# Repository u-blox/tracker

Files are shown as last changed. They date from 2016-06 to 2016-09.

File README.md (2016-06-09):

# Introduction

This code is intended to be used with a Particle Electron board and a PAM-7Q GPS module, plus an ADXL345 accelerometer board (http://www.hobbytronics.co.uk/adxl345-breakout) to allow the GPS module to be powered-down when there is no motion.  It publishes data to the Particle cloud, which can then web-hooked on to the Azure cloud, or other clouds, for analysis.

More instructions to come...

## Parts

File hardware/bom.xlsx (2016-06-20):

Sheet: Tracker
Required
Identifier | Description | Value | Quantity | Manufacturer | Manufacturer Part Number | Supplier Link
MODULE | Particle Electron | --- | 1 | Particle |  | https://store.particle.io/collections/electron
MODULE | GPS module with built-in antenna | --- | 1 | u-blox | PAM-7Q | https://www.u-blox.com/en/product/pam-7q
MODULE | ADXL345 breakout board | --- | 1 | Hobbytronics | ADXL345-BB | http://www.hobbytronics.co.uk/sensors/accelerometer/adxl345-breakout
FET | FET, through hole | --- | 1 | Fairchild | NDP6020P | http://uk.rs-online.com/web/p/mosfet-transistors/8061230/
RESISTOR | Through-hole resistor, 6.5 mm (or less) body length to fit with PCB design | 10k | 1 | --- | --- | http://uk.rs-online.com/web/p/through-hole-fixed-resistors/7077745/
CONNECTOR | PCB header, JST PH B2B series, 2 mm pitch, 2 way, 1 row, through hole | --- | 2 | JST | B2B-PH-K-S(LF)(SN) | http://uk.rs-online.com/web/p/pcb-headers/8201422/
CONNECTOR | PCB socket, 0.1" pitch, 19 contacts, 1 row, through hole | --- | 2 | Samtec | CES-119-02-G-S | http://uk.farnell.com/samtec/ces-119-02-g-s/socket-2-54mm-1x20way/dp/1805643
CONNECTOR | PCB socket, 0.1" pitch, 8 contacts, 1 row, through hole | --- | 1 | Samtec | SSW-108-01-G-S | http://uk.rs-online.com/web/p/pcb-sockets/7655698/
CONNECTOR | PCB socket, 0.1" pitch, 5 contacts, 1 row, through hole | --- | 2 | Harwin | M20-7820546 | http://uk.rs-online.com/web/p/pcb-sockets/6816823/
CONNECTOR | PCB header, 0.1" pitch, 8 way, 1 row, through hole | --- | 1 | Amphenol | 77311-101-08LF | http://uk.rs-online.com/web/p/pcb-headers/6737483/
CONNECTOR | PCB header, 0.1" pitch, N way (you will need only one from the break-off strip), 1 row, through hole | --- | 1 | 3M | 2340-6211TG | http://uk.rs-online.com/web/p/pcb-headers/8277769/
BOX | ABS enclosure, IP54, 121 x 66 x 37 mm | --- | 1 | Hammond | 1591XXCBK | http://uk.rs-online.com/web/p/general-purpose-enclosures/7733139/
BOX ACCESSORIES | PC board self tapping screw no. 4 x 0.25" | --- | 1 bag | Hammond | 1593ATS100 | http://uk.rs-online.com/web/p/enclosure-accessories/0570691/
Optional
Identifier | Description | Value | Quantity | Manufacturer | Manufacturer Part Number | Supplier Link
BATTERY | Li-Po Battery with JST PH Series 2-pin B2B connector (2 mm pitch), 3.7 V, 2000 mAh dimensions 51 mm x 34 mm x 11.3 mm [NOTE 1] | --- | 1 | PKCell | LP103450
BATTERY | 3.7V Li-Po rechargeable battery, 2000 mAh, wire lead terminal [NOTE 2] | --- | 2 | MikroElectronica | MIKROE-1120 | http://uk.rs-online.com/web/p/lithium-rechargeable-battery-packs/7916460/
CONNECTOR | PCB header, JST XH B2B series, 2.5 mm pitch, 2 way, 1 row, through hole [NOTE 3] | --- | 2 | JST | XHP-2 | http://uk.rs-online.com/web/p/pcb-connector-housings/8201611/
CONNECTOR | PCB socket, 0.1" pitch, 1 contact, 1 row, through hole [NOTE 4] | --- | 1 | Amphenol | 68000-401HLF | http://uk.rs-online.com/web/p/pcb-headers/8632706/
CONNECTOR | PCB socket, 0.1" pitch, 19 contacts, 1 row, through hole [NOTE 5] | --- | 2 | Samtec | CES-119-02-G-S | http://uk.farnell.com/samtec/ces-119-02-g-s/socket-2-54mm-1x20way/dp/1805643
CONNECTOR | PCB socket, 0.1" pitch, 8 contacts, 1 row, through hole [NOTE 5] | --- | 1 | Samtec | SSW-108-01-G-S | http://uk.rs-online.com/web/p/pcb-sockets/7655698/
CONNECTOR | PCB socket, 0.1" pitch, 10 contacts, 1 row, through hole [NOTE 5] | --- | 1 | Samtec | SSW-110-01-G-S | http://uk.rs-online.com/web/p/pcb-sockets/7655736/

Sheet: Notes
Notes
You need to chose the appropriate Particle Electron board for the region of the world in which you want the tracker to operate.
For the PCB headers and sockets, provided they are 0.1" pitch and through-hole types, any supplier will do (Samtec, 3M, Harwin, ...).
The ADXL345 board comes with its own PCB header pins which you must solder into place.
The PCB is designed to work with the fitting holes in the 1591XXC Hammond box.
The self-tappling screws come in bags of 100.
The optional battery is required only if you want to try going down the "extra capacity" route (but see WARNING).
The optional PCB sockets are required if you want to populate all of the expansion/test-point headers.

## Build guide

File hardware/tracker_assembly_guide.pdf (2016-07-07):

### Tracker Assembly Guide, Revision 1.2

Introduction
These instruction are for assembly of the Tracker PCBs and mounting them into a base.

Soldering PCB
Note for what follows: J1, J2, J3, J4 and the GND pin are NEVER MOUNTED; the PCB holes are provided for testing only.

The following components need to be soldered into position (and the following order of assembly is suggested):

- sockets for J5 and J6. IMPORTANT: there are two possible types of these sockets: a 2 mm pitch version and a very slightly larger 2.5 mm pitch version. Inserting the 2.5 mm pitch version will require a good shove as the hole spacing is for the 2 mm version. Please pay attention to the orientation of the two types of socket as they are quite different:

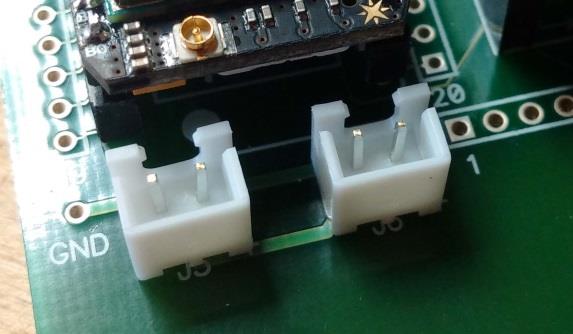
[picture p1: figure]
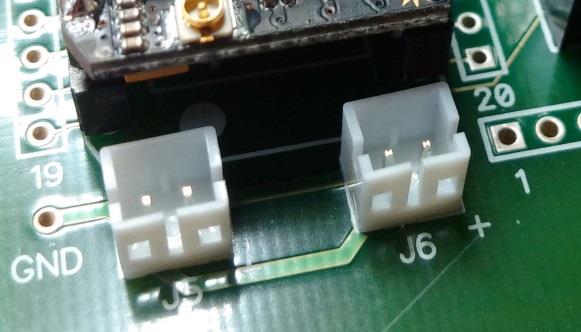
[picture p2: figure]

2 mm pitch connector orientation | 2.5 mm pitch connector orientation
- 10k resistor,
- 2 x 19 row socket for the Particle Electron board [the PCB below shows only 18 holes, there will be 19 holes on the PCBs you get]; NOTE: the legs of the sockets will stick out a bit but they do not require trimming as there is clearance for them in the mounting to the base,
- 2 x 5 row sockets for the ADXL345 board,
- 1 x 8 row socket for the PAM7Q board,
- FET [the FET is actually an NDP6020P, not an FQPF27P06 as marked on the PCB in the picture below],

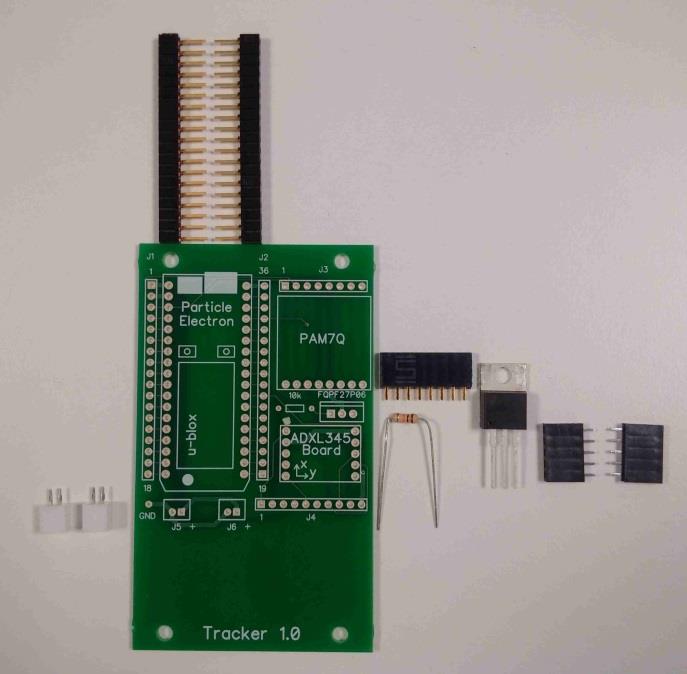
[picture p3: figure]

Suggestion: the best way to hold the 19-way and the pair of 5-way sockets straight while soldering may be to insert the associated sub-assembly into the sockets while doing the soldering.

Soldering Sub-Assemblies
Separately, pins need to be soldered into the following sub-assemblies:
- 8-way pins into the PAM7Q board, oriented so that the pins point downward with the antenna side (the side without the u-blox logo on it, as shown below) upper-most,
- 2 x 5 way pins into the ADXL345 board (break the provided set of 10 into 2 x 5) such that the pins point downward with component side upper-most (as shown below),
- 1 pin into the unpopulated LiPo pin on the Particle Electron board. Suggestion: it may be simplest to push the single pin into the mounted 19-pin socket, then push the Particle Electron board into the socket also and then solder the LiPo pin into the Particle Electron board; this ensures that everything is nicely aligned.

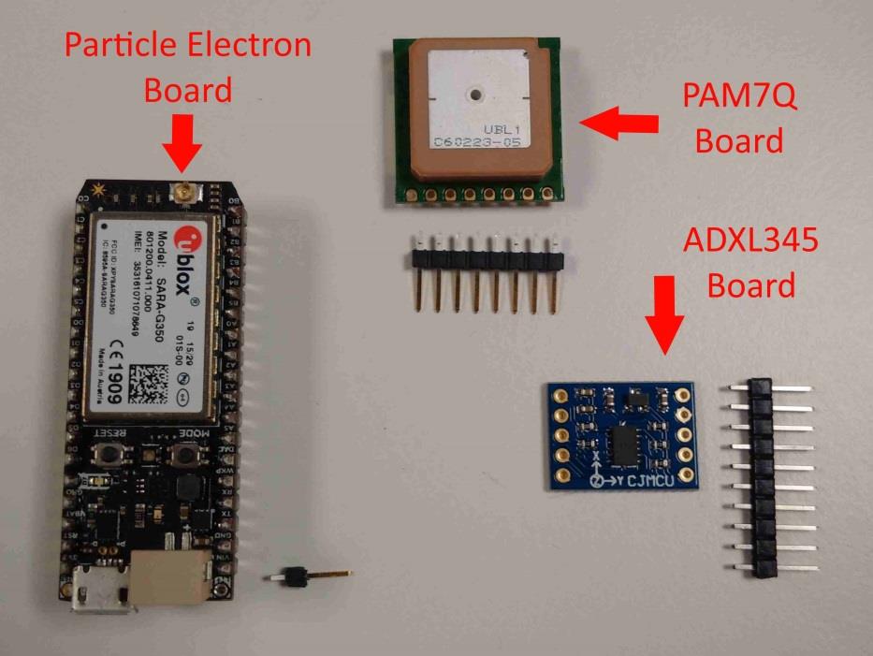
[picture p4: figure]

Assembling Into Base
The assembled PCB should be mounted into the base with four screws:

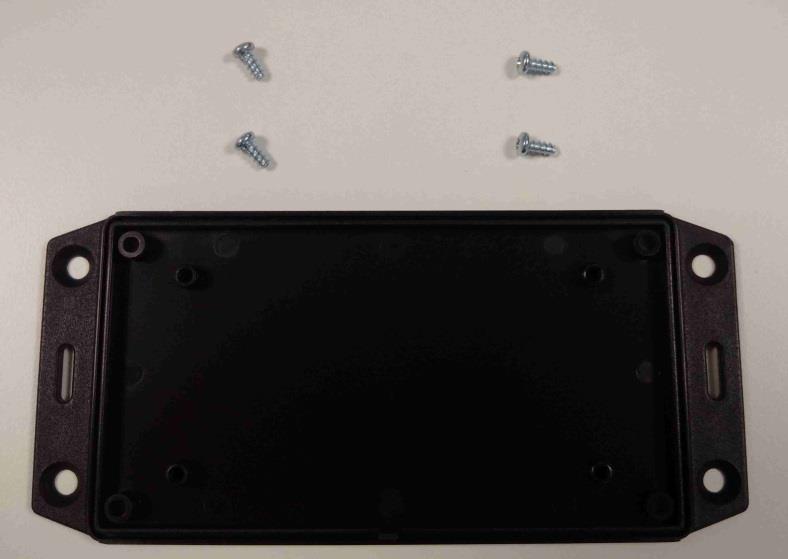
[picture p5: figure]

It doesn’t matter which way round the PCB is mounted into the base.

Assembled Unit Pictures
The assembled unit should look as follows [noting that the board in the picture has 18 holes for each of the two long sockets and the LiPo pin not present, whereas you will have a board with 19 holes on each side and you will add the LiPo pin; these pictures are with the 2 mm pitch J5/J6 socket].

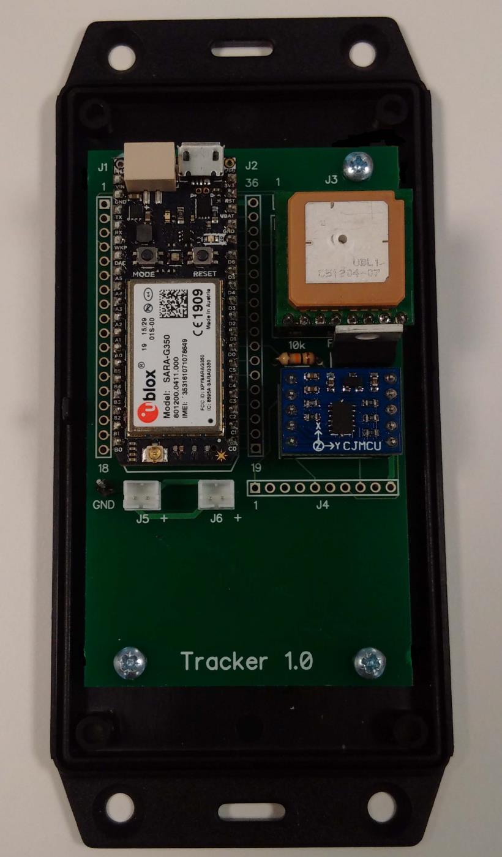
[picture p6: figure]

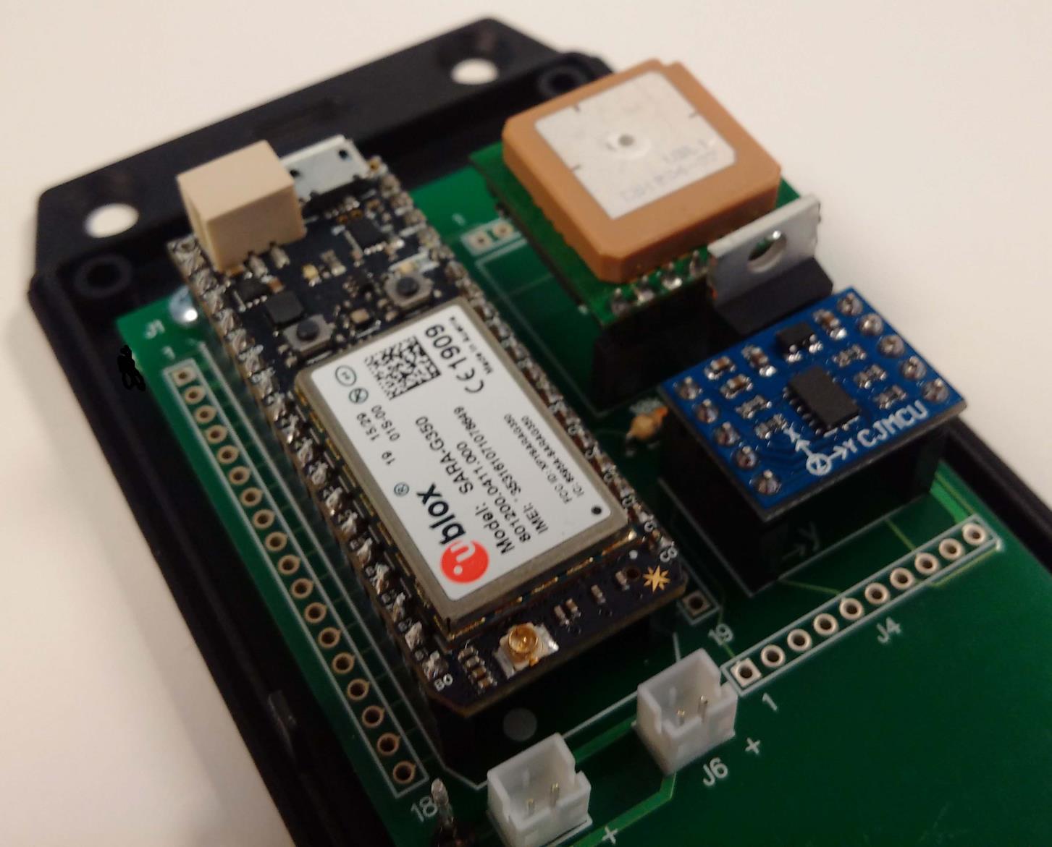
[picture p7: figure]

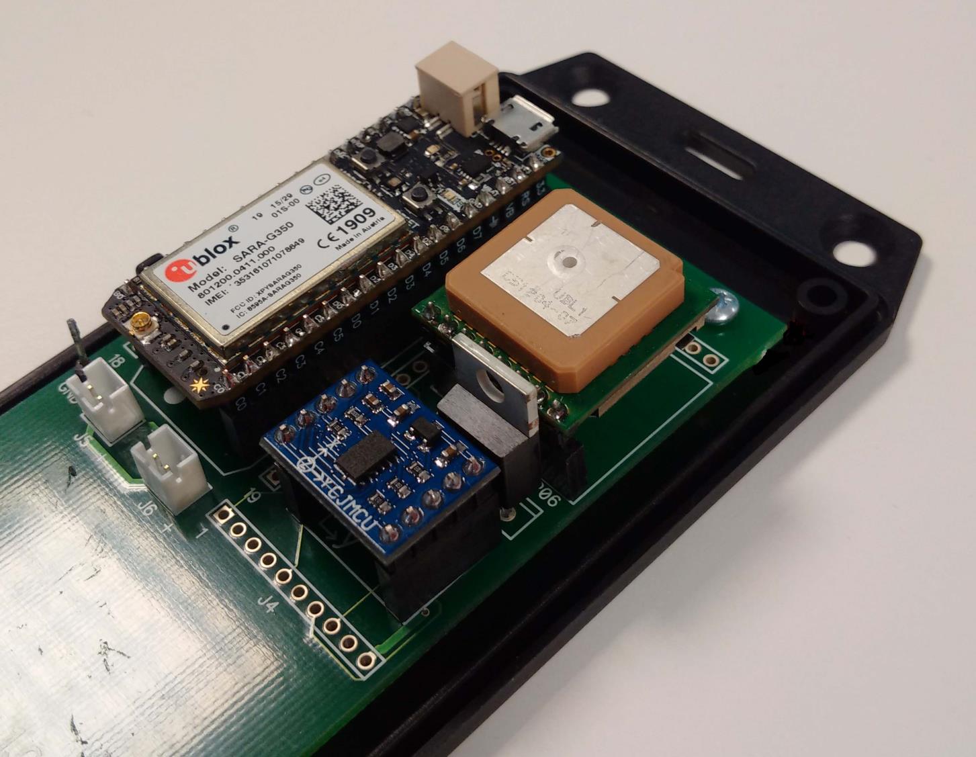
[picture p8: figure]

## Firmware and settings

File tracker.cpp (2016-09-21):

/*
 * Copyright (C) u-blox, author: Rob Meades (rob.meades@u-blox.com)
 * 
 * Licensed under the Apache License, Version 2.0 (the "License");
 * you may not use this file except in compliance with the License.
 * You may obtain a copy of the License at
 * 
 * http://www.apache.org/licenses/LICENSE-2.0
 * 
 * Unless required by applicable law or agreed to in writing, software
 * distributed under the License is distributed on an "AS IS" BASIS,
 * WITHOUT WARRANTIES OR CONDITIONS OF ANY KIND, either express or implied.
 * See the License for the specific language governing permissions and
 * limitations under the License.
 */

/* Tracker
 *
 * This code is for a tracker, borrowing from AssetTracker
 * but using a u-blox GPS module and all through-hole components
 * so that it can be hand assembled (or built using a breadboard).
 * It uses a Particle Electron board (though it is also
 * pin-compatible with a Partilce Photon board since the lower
 * pins are not used), a u-blox PAM7Q GPS module and an ADXL345
 * accelerometer break-out board to establish the GPS position
 * in a power-efficient way.  It reports data to the Particle
 * server and, from there, via webhooks, to anyone who is
 * interested.
 *
 * There are some other differences to AssetTracker:
 *
 * - It is expected that GPS position is sent quite frequently
 *   and so provision is made for use of multiple batteries.
 *   NOTE: BE VERY CAREFUL with this.  There are specific
 *   things you need to do for this to be safe, see the note
 *   in bom.xls.
 * - Processor sleep (sometimes with the modem on, sometimes
 *   with it off) is used to save power between GPS fixes.
 *
 * In order to use power most efficiently, sleep is used in
 * combination with timed operation in the following way:
 *
 * - If, after establishing network time, the time is found to be
 *   less than START_TIME_UNIX_UTC then, the device returns to
 *   deep sleep (modem off, processor clocks and RAM off,
 *   ~0.1 mA consumed) until START_TIME_UNIX_UTC is reached.
 * - If the time is greater than or equal to START_TIME_UNIX_UTC then
 *   the device checks if the working day has begun, i.e. is the time
 *   greater than START_OF_WORKING_DAY_SECONDS and less than
 *   START_OF_WORKING_DAY_SECONDS + LENGTH_OF_WORKING_DAY_SECONDS.
 * - If the time is within the work day then one of two things happens:
 *   - If the time is less than START_TIME_FULL_WORKING_DAY_OPERATION_UNIX_UTC
 *     then the device wakes up only for long enough to get a GPS reading, 
 *     "slow operation" (timing out at SLOW_OPERATION_MAX_TIME_TO_GPS_FIX_SECONDS)
 *     and repeats this SLOW_OPERATION_NUM_WAKEUPS_PER_WORKING_DAY times,
 *     evenly spread throughout the working day.  Between wake-ups the
 *     device returns to deep sleep with the modem off.
 *   - If the time is greater than or equal to
 *     START_TIME_FULL_WORKING_DAY_OPERATION_UNIX_UTC then the device remains
 *     awake for all of the working day, putting the processor to sleep and
 *     keeping the modem registered with the network if wake-ups are frequent
 *     enough, so that we can collect and report position for the full working day.
 * - If the time is not within the working day then the device returns to
 *   deep sleep, with modem off, until the start of the next working day.
 *
 * The default timings are set so that the device wakes-up in slow operation and
 * then goes into full working day operation a few days later. This was for a show
 * where the trackers were installed a few days before the start of the show and
 * we wanted to monitor that they were OK but not consume a lot of battery power.
 * By judicious choice of:
 *
 *  - START_TIME_UNIX_UTC
 *  - START_TIME_FULL_WORKING_DAY_OPERATION_UNIX_UTC
 *  - START_OF_WORKING_DAY_SECONDS
 *  - LENGTH_OF_WORKING_DAY_SECONDS
 *  - SLOW_OPERATION_NUM_WAKEUPS_PER_WORKING_DAY
 *
 * ... you should be able to achieve the tracker behaviour you want.  To always
 * get slow operation, set START_TIME_FULL_WORKING_DAY_OPERATION_UNIX_UTC to a
 * time far in the future.  To always get full monitoring throughout the working
 * day, set START_TIME_FULL_WORKING_DAY_OPERATION_UNIX_UTC to START_TIME_UNIX_UTC.
 * To set the working day to be 24 hours, set START_OF_WORKING_DAY_SECONDS to 0 and
 * LENGTH_OF_WORKING_DAY_SECONDS to 3600.
 *
 * MESSAGES
 *
 * The chosen message formats are highly compressed to
 * save data and are of the following form:
 *
 * "gps":"353816058851462;51.283645;-0.776569;1465283731;1;5.15"
 *
 * ...where the first item is the 15-digit IMEI of the device, the
 * second one the latitude in degrees as a float, the third one the
 * longitude in degrees as a float, then there's the timestamp
 * in Unix time (UTC) and finally the last two, inserted at the end
 * to preserve backwards-compatibility with previous implementations of this
 * messaging system; these are a 1 if the reading was triggered due to the
 * accelerometer indicating motion (0 otherwise) and then the horizontal
 * dilution of position (i.e. accuracy) as a float.  All fields up to and
 * including the timestamp must be present; if either of the fields after the
 * timestamp need to be included then both must be included. This message is
 * queued at every wakeup, if a fix is achieved.
 * 
 * "telemetry":"353816058851462;80.65;-70;1465283731;1"
 *
 * ...where the first item is the 15-digit IMEI, the second one
 * the battery left as a percentage, the third the signal strength
 * in dBm and then the timestamp in Unix time (UTC).  After the timestamp,
 * for backwards compatibility with earlier versions of this protocol,
 * is the SW version. All fields except the SW version must be present.
 * This is sent periodically when the device wakes up from deep sleep and
 * every TELEMETRY_PERIOD_SECONDS seconds thereafter.
 *
 * NOTE: in addition to the above there is a "stats" message with
 * a similar format. This is used to send statistics purely as far
 * as the Particle web server to assist with debugging this code.
 * See queueStatsReport() for more details.
 *
 * NOTE: if you want to use a different message format, maybe
 * using a more standard (though less efficient) JSON approach,
 * simply modify queueTelemeteryReport(), queueGpsReport()
 * (and, if required, queueStatsReport()) to match.
 *
 * NOTE on webhooks: Particle webhooks are really neat but they
 * can be a bit confusing to code.  First of all, when you
 * use the "json" field, you must quote a key/value pair, so even
 * if you only want to send on what Particle received (using the
 * {{PARTICLE_EVENT_VALUE}}) you can't.
 *
 * Then, you will see in your Particle web log something like:
 *
 * hook-sent/telemetry   undefined   time-date
 *
 * The "undefined" bit looks bad but actually it's normal; hook-sent
 * is just an indication that your info was sent on, it contains
 * no data itself, hence the "undefined".
 *
 * Lastly, if you connect to a site that reflects back what it
 * receives, you will see a hook-response something like:
 *
 * {"data":{"telemetry":"the stuff you actually sent","ttl":"60","published_at":"2016-06-08T09:27:10.130Z","coreid":"particle-internal","name":"hook-response/telemetry/0"}
 *
 * What the other end is actually _receiving_ is the value part
 * of the "data" key, so in this example:
 *
 * "telemetry":"the stuff you actually sent"
 *
 * The rest is just stuff that Particle inserts for your info.
 * Note that any quotes inside the stuff you actually sent will
 * be converted to &quot; (URL-style) so you will need to make
 * sure that whoever is parsing your data can cope with that.
 */

#include "accelerometer.h"

/****************************************************************
 * CONDITIONAL COMPILATION OPTIONS
 ***************************************************************/

/// Define this to force a development build, which sends
// stats and initiates "working day" operation straight away.
//#define DEV_BUILD

/// Define this to do GPS readings irrespective of the state of the
// accelerometer.
//#define DISABLE_ACCELEROMETER

/// Define this if using the USB port for debugging.
#define USB_DEBUG

/// Define this if a 2D GPS fix is sufficient.
#define GPS_FIX_2D

/// Define this to skip doing anything with the cellular connection.
//#define DISABLE_CELLULAR_CONNECTION

/// Define this to send stats at each GPS attempt
#define ENABLE_SEND_STATS_AT_GPS_ATTEMPT

/****************************************************************
 * CONFIGURATION MACROS
 ***************************************************************/

/// The start time for the device (in Unix, UTC).
// If the device wakes up before this time it will return
// to deep sleep.  After this time it will work in slow operation,
// waking up at SLOW_MODE_INTERVAL_SECONDS after the start of the
// working day for up to SLOW_OPERATION_MAX_TIME_TO_GPS_FIX_SECONDS
// each time.
// Use http://www.onlineconversion.com/unix_time.htm to work this out.
#ifdef DEV_BUILD
# define START_TIME_UNIX_UTC 1469340000 // 24th July 2016 @ 06:00 UTC
#else
# define START_TIME_UNIX_UTC 1473933600 // 15th September 2016 @ 12:00 UTC
#endif

/// The start time for full working day operation (in Unix, UTC).
// After this time the device will be awake for the whole working day and send reports
// as necessary.
// This time must be later than or equal to START_TIME_UNIX_UTC.
// Use http://www.onlineconversion.com/unix_time.htm to work this out.
#ifdef DEV_BUILD
# define START_TIME_FULL_WORKING_DAY_OPERATION_UNIX_UTC 1469340000 // 24th July 2016 @ 06:00 UTC
#else
# define START_TIME_FULL_WORKING_DAY_OPERATION_UNIX_UTC 1473933600 // 15th September 2016 @ 12:00 UTC
#endif

/// The version string of this software (an incrementing integer).
#define SW_VERSION 8

/// The minimum time for which we go to deep sleep.  If the sleep time
// is less than this we will use clock-stop sleep instead
#define MINIMUM_DEEP_SLEEP_PERIOD_SECONDS 600

/// The maximum amount of time to hang around waiting for a
// connection to the Particle server.
#define WAIT_FOR_CONNECTION_SECONDS 180

/// How long to wait for things to sort themselves out on the
// USB port after waking up from sleep.
#ifdef USB_DEBUG
# define WAIT_FOR_WAKEUP_TO_SETTLE_SECONDS 5
#else
# define WAIT_FOR_WAKEUP_TO_SETTLE_SECONDS 0
#endif

/// How long to wait for the Particle server to respond to
// a time sync request
#define TIME_SYNC_WAIT_SECONDS 10

/// If the system cannot establish time by talking to the 
// Particle server, wait this long and try again.
#define TIME_SYNC_RETRY_PERIOD_SECONDS 30

/// The time between wake-ups as a result of motion being detected.
#define MIN_MOTION_PERIOD_SECONDS 30
#define MAX_MOTION_PERIOD_SECONDS (60 * 5)

/// The amount of time to wait for a publish to complete.
#define WAIT_FOR_PUBLISH_SECONDS 60

/// The time we stay awake waiting for GPS to get a fix every
// MOTION_PERIOD_SECONDS.
// NOTE: the GPS device may stay awake for longer, this is only
// the period for which the processing system running this
// code stays awake waiting.
#define GPS_FIX_TIME_SECONDS 20

/// The interval at which we check for a fix, within GPS_FIX_TIME_SECONDS
#define GPS_CHECK_INTERVAL_SECONDS 5

/// The largest wake-up period once we're past START_TIME_UNIX_UTC.
#define MAX_WAKEUP_PERIOD_SECONDS (3600 * 2)

/// The periodicity of telemetry reports.
#define TELEMETRY_PERIOD_SECONDS MAX_WAKEUP_PERIOD_SECONDS

/// The periodicity of stats reports.
#define STATS_PERIOD_SECONDS TELEMETRY_PERIOD_SECONDS

/// The report period in seconds.  At this interval the
// queued-up records are sent (though they may be sent
// earlier if QUEUE_SEND_LEN is reached).
#define REPORT_PERIOD_SECONDS (60 * 10)

/// The queue length at which to begin sending records.
#ifdef ENABLE_SEND_STATS_AT_GPS_ATTEMPT
# define QUEUE_SEND_LEN 8
#else 
# define QUEUE_SEND_LEN 4
#endif

/// The size of a record.
#define LEN_RECORD 120

/// The minimum possible value of Time (in Unix, UTC), used
// to check the sanity of our RTC time.
#define MIN_TIME_UNIX_UTC 1451606400 // 1 Jan 2016 @ midnight

/// The maximum number of consecutive connection failures
// before we take further action.
#define MAX_NUM_CONSECUTIVE_CONNECT_FAILURES 5

/// The number of times to wake-up during the working day when in slow operation.
#define SLOW_OPERATION_NUM_WAKEUPS_PER_WORKING_DAY 1

/// The maximum amount of time to wait for a GPS fix to be established while we are in
// slow operation.  After this time, or as soon as a GPS fix has been established
// and transmitted, we can go to deep sleep.
#define SLOW_OPERATION_MAX_TIME_TO_GPS_FIX_SECONDS (60 * 10)

/// Start of day in seconds after midnight UTC.
#define START_OF_WORKING_DAY_SECONDS (3600 * 0) // 00:00 UTC

/// Duration of a working day in seconds.
#define LENGTH_OF_WORKING_DAY_SECONDS (3600 * 24) // 24 hours

/// Modem wake-up delay.
#define MODEM_POWER_ON_DELAY_MILLISECONDS 1000

/// The accelerometer activity threshold (in units of 62.5 mg).
#define ACCELEROMETER_ACTIVITY_THRESHOLD 3

/// The maximum time to wait for a GPS fix
#define GPS_MAX_ON_TIME_SECONDS (60 * 10)

/// GPS module power on delay.
#define GPS_POWER_ON_DELAY_MILLISECONDS 500

/// How long to wait for responses from the GPS module after sending commands.
#define GPS_DELAY_MILLISECONDS 100

/// How long to wait for an Ack message back from the GPS module.
#define GPS_WAIT_FOR_ACK_MILLISECONDS 3000

/// How long to wait for non-ack responses from the GPS module.
#define GPS_WAIT_FOR_RESPONSE_MILLISECONDS 2000

/// Allow a gap between characters read from GPS when in command/response mode.
#define GPS_INTER_CHARACTER_DELAY_MILLISECONDS 50

/// The offset at the start of a UBX protocol message.
#define GPS_UBX_PROTOCOL_HEADER_SIZE ((uint32_t) 6)

/// The minimum number of satellites for which we want to have ephemeris data.
#define GPS_MIN_NUM_EPHEMERIS_DATA 5

/// Something to use as an invalid angle.
#define GPS_INVALID_ANGLE 999999999

/// Something to use as an invalid HDOP.
#define GPS_INVALID_HDOP 999999999

/// Amount of time considered as being in motion after an initial accelerometer motion
#define IN_MOTION_TIME_SECONDS (60 * 10)

/***************************************************************
 * OTHER MACROS
 ***************************************************************/

/// A magic string to indicate that retained RAM has been initialised.
#define RETAINED_INITIALISED "RetInit"

/// The length of the IMEI, used as the device ID.
#define IMEI_LENGTH 15

/// Work out the number of seconds between each wake-up in slow mode.
#define SLOW_MODE_INTERVAL_SECONDS (LENGTH_OF_WORKING_DAY_SECONDS / (SLOW_OPERATION_NUM_WAKEUPS_PER_WORKING_DAY + 1))

/****************************************************************
 * TYPES
 ***************************************************************/
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
void loop() {
    bool forceSend = false;
    bool wakeOnAccelerometer = false;
    bool atLeastOneGpsReportSent = false;
    bool inMotion = false;
    bool accelerationDetected = false;
    bool stillInMotion = false;
    bool fixAchieved = false;
    bool sendFailure = false;
    float latitude = GPS_INVALID_ANGLE;
    float longitude = GPS_INVALID_ANGLE;
    float elevation = 0;
    float hdop = GPS_INVALID_HDOP;

    // Wait for USB to sort itself out
    delay(WAIT_FOR_WAKEUP_TO_SETTLE_SECONDS * 1000);
    
    // Add a new log flag entry for this loop
    addLogFlagsEntry();
    clearLogFlag(LOG_FLAG_STARTUP_NOT_LOOP_ENTRY);
    
    // Set the GPS log flag (as otherwise it won't be
    // set unless GPS is toggled on this loop)
    if (gpsIsOn()) {
        setLogFlag(LOG_FLAG_GPS_ON_NOT_OFF);
    }
    
    // This only for info
    r.numLoops++;
    LOG_MSG("\n-> Starting loop %d at %s UTC, having power saved since %s UTC (%d second(s) ago).\n", r.numLoops,
            Time.timeStr().c_str(), Time.timeStr(r.powerSaveTime).c_str(), Time.now() - r.powerSaveTime);

    // If we are in slow operation override the stats timer period
    // so that it is more frequent; it is useful to see these stats in
    // this "slow operation" case to check that the device is doing well.
    // Also make sure that we request a GPS fix, irrespective of whether
    // we're moving or not, as that is also useful data.
    if (Time.now() < START_TIME_FULL_WORKING_DAY_OPERATION_UNIX_UTC) {
        statsPeriodSeconds = MIN_MOTION_PERIOD_SECONDS;
        r.gpsFixRequested = true;
    } else {
        setLogFlag(LOG_FLAG_START_TIME_FULL_WORKING_DAY_OPERATION_PASSED);
    }

    // Having valid time is fundamental to this program and so, if time
    // has not been established try to establish it again
    if (establishTime()) {

        // Add up the time we were in power save mode (for info)
        if (r.powerSaveTime != 0) {
            r.totalPowerSaveSeconds += Time.now() - r.powerSaveTime;
            r.powerSaveTime = 0;
        }

        // If sleepStartSeconds was recorded, for some reason, before we
        // established time then it will be out of wack.  In this case,
        // give it a sensible time
        if (r.sleepStartSeconds < MIN_TIME_UNIX_UTC) {
            r.sleepStartSeconds = Time.now();
        }

        // Check if we should be awake at all
        if (Time.now() >= START_TIME_UNIX_UTC) {
            uint32_t secondsSinceMidnight = Time.hour() * 3600 + Time.minute() * 60 + Time.second();

            setLogFlag(LOG_FLAG_START_TIME_PASSED);
            
            // Check if we are inside the working day
            if ((secondsSinceMidnight >= START_OF_WORKING_DAY_SECONDS) &&
                (secondsSinceMidnight <= START_OF_WORKING_DAY_SECONDS + LENGTH_OF_WORKING_DAY_SECONDS)) {
                    
                LOG_MSG("It is during the working day.\n");
                setLogFlag(LOG_FLAG_IN_WORKING_DAY);

                // Respond to interrupts
                wakeOnAccelerometer = true;

                // See if we've moved
                accelerationDetected = handleInterrupt();
                stillInMotion = stillWithinMotionDelaySinceLastAcceleration(r.lastAccelerometerNudge, Time.now());
                inMotion = (accelerationDetected || stillInMotion);
                if (inMotion) {
                  r.gpsFixRequested = true;
                  r.lastMotionSeconds = Time.now();
                  if (accelerationDetected) {
                    r.lastAccelerometerNudge = r.lastMotionSeconds;
                    LOG_MSG("*** Acceleration was detected.\n");
                  } else {
                    LOG_MSG("*** Motion was detected based on time.\n");
                  }
                  r.numLoopsMotionDetected++;
                  setLogFlag(LOG_FLAG_MOTION_DETECTED);
                }

                // First of all, check if this is a wake-up from a previous sleep
                // where we set a minimum sleep period
                if (Time.now() >= r.sleepStartSeconds + r.minSleepPeriodSeconds) {
                    // If we're outside the minimum sleep period, reset all these
                    // variables to defaults for this wake-up
                    r.sleepForSeconds = MIN_MOTION_PERIOD_SECONDS;
                    r.minSleepPeriodSeconds = MIN_MOTION_PERIOD_SECONDS;
                    r.modemStaysAwake = false;

                    // Queue a telemetry report, if required
                    if (Time.now() - r.lastTelemetrySeconds >= TELEMETRY_PERIOD_SECONDS) {
                        r.lastTelemetrySeconds = Time.now();
                        // Switch the modem on for this so that we can get the RSSI and,
                        // in any case, we will be forcing a send
                        Cellular.on();
                        delay(MODEM_POWER_ON_DELAY_MILLISECONDS);
                        queueTelemetryReport();
                        LOG_MSG("Forcing a send.\n");
                        forceSend = true;
                    }
    
                    // Queue a stats report, if required
                    if (Time.now() - r.lastStatsSeconds >= statsPeriodSeconds) {
                        r.lastStatsSeconds = Time.now();
                        queueStatsReport();
                    }
    
                    // Queue a GPS report if we're in motion or can't tell if we're in motion
                    if (r.gpsFixRequested || !accelerometerConnected) {
                        r.numLoopsLocationNeeded++;
                        
                        if (!accelerometerConnected) {
                            LOG_MSG("No accelerometer, getting GPS reading every time.\n");
                        }
                        if (gpsIsOn()) {
                            LOG_MSG("Still trying to get a GPS fix from last time.\n");
                        }
    
                        r.numLoopsGpsOn++;
                        // Get the latest output from GPS
                        fixAchieved = gpsUpdate(&latitude, &longitude, &elevation, &hdop);
                        if (fixAchieved) {
                            r.numLoopsGpsFix++;
                            r.numLoopsLocationValid++;
                            r.lastGpsSeconds = Time.now();
                            queueGpsReport(latitude, longitude, inMotion, hdop);
                        }
                    }
    
                    // If GPS meets the power-save criteria, switch it off
                    if (!inMotion && gpsIsOn() && gpsCanPowerSave()) {
                        gpsOff();
                    }
    
#ifdef ENABLE_SEND_STATS_AT_GPS_ATTEMPT
                    // If a fix was requested, and now that we have the GPS stats (which were
                    // populated in the gpsCanPowerSave() call), queue a stats report with
                    // the data in.
                    if (r.gpsFixRequested) {
                        queueStatsReport();
                    }
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

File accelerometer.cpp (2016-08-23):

/*
 * Copyright (C) u-blox, author: Rob Meades (rob.meades@u-blox.com)
 * 
 * Licensed under the Apache License, Version 2.0 (the "License");
 * you may not use this file except in compliance with the License.
 * You may obtain a copy of the License at
 * 
 * http://www.apache.org/licenses/LICENSE-2.0
 * 
 * Unless required by applicable law or agreed to in writing, software
 * distributed under the License is distributed on an "AS IS" BASIS,
 * WITHOUT WARRANTIES OR CONDITIONS OF ANY KIND, either express or implied.
 * See the License for the specific language governing permissions and
 * limitations under the License.
 */

#include "accelerometer.h"

#define ACCELEROMETER_ADDRESS   ((uint8_t) 0x53)

// ----------------------------------------------------------------
// INTERRUPT HANDLER
// ----------------------------------------------------------------

/// Interrupt handler for the accelerometer
Accelerometer::EventsBitmap_t Accelerometer::handleInterrupt(void)
{
    Accelerometer::EventsBitmap_t eventsBitmap = Accelerometer::EVENT_NONE;
    char eventReg;

    // Read what happened
    Wire.beginTransmission(ACCELEROMETER_ADDRESS);
    Wire.write(0x30);
    Wire.endTransmission();
    
    if (Wire.requestFrom(ACCELEROMETER_ADDRESS, (uint8_t) 1) == 1) {
        eventReg = Wire.read();

        // Activity
        if (eventReg & 0x10)
        {
            eventsBitmap = (Accelerometer::EventsBitmap_t) (eventsBitmap | Accelerometer::EVENT_ACTIVITY);
        }
    
        // Double tap
        if (eventReg & 0x20)
        {
            eventsBitmap = (Accelerometer::EventsBitmap_t) (eventsBitmap | Accelerometer::EVENT_DOUBLE_TAP);
        }
    
        // Single tap
        if (eventReg & 0x40)
        {
            eventsBitmap = (Accelerometer::EventsBitmap_t) (eventsBitmap | Accelerometer::EVENT_SINGLE_TAP);
        }
    }
    
    return eventsBitmap;
}

// ----------------------------------------------------------------
// GENERIC PRIVATE FUNCTIONS
// ----------------------------------------------------------------

/// Constructor
Accelerometer::Accelerometer(void) {
}

/// Destructor
Accelerometer::~Accelerometer(void) {
}

/// Debug
void Accelerometer::readDeviceRegisters(uint8_t address, uint32_t reg, uint8_t numValues)
{
    uint8_t numBytes;

    Serial.printf("Device 0x%02x: ", address);
    Wire.beginTransmission(address);
    numBytes = Wire.write(reg);
    Wire.endTransmission();
    
    if (numBytes == 1) {
        numBytes = Wire.requestFrom(address, numValues);
        if (numBytes != numValues) {
            Serial.printf("(read %d out of %d value(s) requested) ", numBytes, numValues);
        }
        
        for (uint8_t x = 0; x < numBytes; x++) {
            Serial.printf("%02x: %02x", (int) (reg + x), Wire.read());
            if ((x + 1) < numBytes)
            {
                Serial.printf(", ");
            }
        }
        Serial.printf(".\n");
    } else {
        Serial.printf("unable to write address of register 0x%02x.\n", reg);
    }

}

// ----------------------------------------------------------------
// PUBLIC FUNCTIONS
// ----------------------------------------------------------------

/// Initial setup of the accelerometer
bool Accelerometer::begin(void)
{
    uint8_t bytesWritten;
    bool success = false;
    uint8_t data[2];

    // Start the I2C interface
    Wire.setSpeed(CLOCK_SPEED_100KHZ);
    Wire.begin();

    // Reading register 0x00 should get us back 0xE5
    Wire.beginTransmission(ACCELEROMETER_ADDRESS);
    bytesWritten = Wire.write(0x00);
    Wire.endTransmission();
    if (bytesWritten == 1) {
        if (Wire.requestFrom(ACCELEROMETER_ADDRESS, (uint8_t) 1) == 1) {
            data[0] = Wire.read();
            if (data[0] == 0xE5) {
                success = true;
                Serial.printf("Accelerometer is connected at I2C address 0x%02x.\n", ACCELEROMETER_ADDRESS);
            } else {
                Serial.printf("Accelerometer: I2C address 0x%02x, reading value of register 0x00 got 0x%02x but expected 0xE5.\n",
                              ACCELEROMETER_ADDRESS, data[0]);
            }
        } else {
            Serial.printf("Accelerometer: I2C address 0x%02x, timeout reading value of register 0x00.\n", ACCELEROMETER_ADDRESS);
        }
    } else {
        Serial.printf("Accelerometer: I2C address 0x%02x, unable to write the address of register 0x00.\n", ACCELEROMETER_ADDRESS);
    }

    return success;
}

/// Configure the accelerometer.
bool Accelerometer::configure(void)
{
    uint8_t bytesWritten;
    bool success = false;
    uint8_t data[2];

    // Setup the ADI XL345 accelerometer
    // Reading register 0x00 should get us back 0xE5
    Wire.beginTransmission(ACCELEROMETER_ADDRESS);
    bytesWritten = Wire.write(0x00);
    Wire.endTransmission();
    if (bytesWritten == 1) {
        if (Wire.requestFrom(ACCELEROMETER_ADDRESS, (uint8_t) 1) == 1) {
            data[0] = Wire.read();
            if (data[0] == 0xE5) {
                success = true;
                
                Serial.printf("Accelerometer is connected at I2C address 0x%02x.\n", ACCELEROMETER_ADDRESS);
                
                // Set up the interrupts: activity only
                data[0] = 0x2E;
                data[1] = 0x00;  // Disable all interrupts for the moment
                Wire.beginTransmission(ACCELEROMETER_ADDRESS);
                bytesWritten = Wire.write(data, 2);
                Wire.endTransmission(true);
            
                if (bytesWritten != 2) {
                    success = false;
                    Serial.printf("Accelerometer: I2C address 0x%02x, unable to set interrupt register (0x%02x) to value 0x%02x.\n",
                                  ACCELEROMETER_ADDRESS, data[0], data[1]);
                }

                data[0] = 0x24;  // Activity threshold
                data[1] = 0x10;  // Low
                Wire.beginTransmission(ACCELEROMETER_ADDRESS);
                bytesWritten = Wire.write(data, 2);
                Wire.endTransmission(true);

                if (bytesWritten != 2) {
                    success = false;
                    Serial.printf("Accelerometer: I2C address 0x%02x, unable to set activity threshold register (0x%02x) to value 0x%02x.\n",
                                  ACCELEROMETER_ADDRESS, data[0], data[1]);
                }
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

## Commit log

2016-06-10 Add revision 1.0 schematics and PCB.
    [BoardOutline.gbr, Bottom.gbr, BottomAssy.gbr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]
2016-06-11 Update schematic and PCB to wire the JST connector to V LiPo not V In. Add all the required components to the pattern and component files. Add the bill of materials spreadsheet.
    [bom.xlsx]
2016-06-11 Switch to CPP file.
2016-06-11 Move Gerber and drill files into an exported folder.
    [BoardOutline.gbr, Bottom.gbr, BottomAssy.gbr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]
2016-06-12 Version that works with the accelerometer and has the concept of a start time and a work day (though the latter is currently disabled and all of this needs more testing).
2016-06-13 Added stats and fixed interrupt silliness.
    [accelerometer.cpp, tracker.cpp]
2016-06-14 Sort start/end of day calculation and increase accelerometer sensitivity again.
2016-06-17 Remove unnecessary interrupt handling. Add stats reporting so that we can see what's happening without having to connect USB interface. Correct the sense of the "GPS on" pin. Increase accelerometer t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
    [Bottom.gbr, BottomMask.gbr, Through.drl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]
2016-06-20 Change FET name to correct one (now NDP6020P, not FQPF27P06). Update BoM. Add assembly guide.
    [bom.xlsx]
2016-06-20 Add interface to set Accelerometer threshold and enable/disable interrupts. Add use of retained memory to tracker in order to maintain stats across resets. Add memory guards to make sure that no memo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
    [accelerometer.cpp, tracker.cpp]
2016-06-21 Corrections to slow mode wake-up time and a few other minor bug fixes.
    [tracker.cpp]
2016-06-22 Update to match labelling of the FET (no electrical change).
    [Bottom.gbr, BottomMask.gbr, Top.gbr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]
2016-06-22 Additional information on assembly order and the two sorts of battery connector.
2016-06-22 Fixes for slow operation mode. This SW version has been programmed into the 5 test devices I built this afternoon.
    [tracker.cpp]
2016-06-23 Remove memory guard checks, having seen no problems in recent days. Tidy send() functionality into a function of its own. Flag if the accelerometer is not connected and, if it is not, assume that GPS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
    [accelerometer.cpp, tracker.cpp]
2016-06-24 Remove disable interrupts for sleep with modem awake (which was a counter-functional idea). Force us to go back to sleep when awoken early to workaround issue that the WKP pin is always able to wake 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
    [tracker.cpp]
2016-06-27 Fix bug in TinyGPS where I hadn't hacked out GPRMC properly. Reduce accelerometer threshold to 3 to make sure it really does trigger. Add a switch for the DEV_BUILD to make it simple to switch to pro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
    [tracker.cpp]
2016-06-30 Follow advice from Marcel Durler on which UBX GPS commands I need. Change LOG to MSG_LOG to avoid conflict with another macro.
    [tracker.cpp]
2016-07-01 No longer use tinyGPS, all UBX format messages. Change GPS update mechanism so that it polls every 5 seconds and sleeps between checking.
    [tracker.cpp]
2016-07-02 Release 1 version, ready to go I think. Stats are now sent at the telemetry interval even in a non-DEV build, and are also sent at the WAKEUP_PERIOD_SECONDS if we are in slow mode, so that we can cle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
2016-07-06 SW version 2: if GPS is on, make sure that I do attempt to get a fix and then shut it off (a fix is obtained); otherwise we will drain power unnecessarily. Change the pre-show wake-up duration to 10 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
    [tracker.cpp]
2016-07-07 Make assembly guide more generic.
2016-07-20 Switch webhooks to production server.
2016-07-20 First draft of new version targeted more at a proper tracker, with more power-saving potential.
2016-07-22 Version with improved power saving (now goes to deep sleep much more of the time).
2016-07-23 Various fixes, this version looking good for final version.
    [accelerometer.cpp, tracker.cpp]
2016-07-24 Fixed issues with slow-mode wake-up, this is now the next test candidate.
    [tracker.cpp]
2016-07-25 Fix check for transition from slow-mode to full-working-day mode so that it happens at the earliest point.
    [tracker.cpp]
2016-07-25 Don't force a GPS report at the telemetry interval as it wastes power.
2016-07-26 Increment SW version number to 4 and also store in battery-backed RAM at a reset so that we can cross-check what SW version the battery-backed RAM contents was written by (hence avoiding weirdness wh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
    [tracker.cpp]
2016-07-27 Correct use of sleep limits check (it mustn't stop the long sleep periods when START_TIME_UNIX_UTC or START_TIME_FULL_WORKING_DAY_OPERATION_UNIX_UTC has not yet been reached). This version has now le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
    [tracker.cpp]
2016-07-29 Changes to workaround what we believe is a failure to wake-up from deep sleep in the Particle code under some circumstances.
    [tracker.cpp]
2016-08-01 Always wake-up on accelerometer if it is during the working day as a "get out of sleep free" in case the sleep wake-up doesn't work. Also add an event logging mechanism to store things that have happ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
    [tracker.cpp]
2016-08-02 Switch modem off before entering deep sleep. This seems to workaround the problem where calling deep sleep with a wake-up delay of 30 seconds causes the system to completely die (not even respond to 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
    [tracker.cpp]
2016-08-02 Implement the accepted workaround for issue https://github.com/spark/firmware/issues/1075. Shift the SW version number back to 7 as 8 was not released and I can test the upgrade process by changing S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
    [tracker.cpp]
2016-08-03 Increase connect timeout to 180 seconds and GPS timeout to 10 minutes. Fix stats reports so that they include GPS data. Take out the "wake-up on interrupts" belt and braces in the "unable to establis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
    [tracker.cpp]
2016-08-04 Hacked off with deep sleep now. The workaround doesn't appear to workaround. Added MINIMUM_DEEP_SLEEP_PERIOD_SECONDS, set to 10 minutes, and we only go to clock-stop sleep if the sleep duration is le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
    [tracker.cpp]
2016-09-21 Tracking previously done on acceleration. Extended to track when in motion too.
